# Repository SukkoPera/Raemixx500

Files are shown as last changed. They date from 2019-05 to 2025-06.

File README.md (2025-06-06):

# Rämixx500
Rämixx500 is an Open Hardware remake of the Commodore Amiga 500+ mainboard, revision 8A.1.

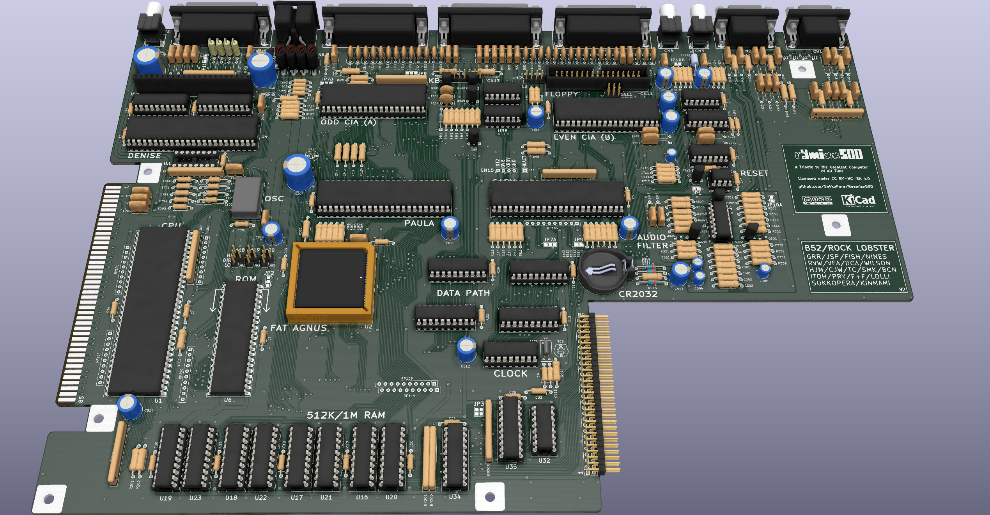
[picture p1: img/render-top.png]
Board


## Summary
Many Amiga 500+ computers are suffering an early death because of the built-in barrel battery that powers their internal real-time clocks. Such batteries have long exceeded their planned lives and in many cases have started to leak alkaline liquids over the mainboard, corroding copper traces and destroying components.

This damage can sometimes be repaired trivially, but many times it requires a lot of time and effort. Sometimes it adds up to other damage occurred over time and so it would just be better to have a new board built with new components to move the few critical chips over. Amiga mainboards haven't been produced for the last 30 years, but they are relatively simple by today's standards, thus an amateur project to make new ones was started.

There are other projects with the same goal out there, but none of them is Open Source and none of them comes with both schematics and board. This is a big advantage, since anyone can modify the board and make new improved versions, as long as they release their modifications it with the same license. I have come up with [some ideas for improvements](https://github.com/SukkoPera/Raemixx500/issues/14), feel free to help :).

The first version of the board was released in April 2020 as untested, in the hope that someone from the Amiga "Community" would jump in and help with the testing. Well, that took quite some time but in the end someone finally understood that Open Hardware is about trying to do your part rather than coming up with [heaps of useless talking and moaning](https://news.ycombinator.com/item?id=22887349) or [blatant stealing](https://retrotechlyfe.com/home/ols/products/commodore-amiga-500-computer-motherboard-logic-board-premium-gold-immersed-traces-stellar-signal-integrity) and allowed this project to reach the next milestone. So despite knowing he could be jumping into the void, fellow Italian living in Japan Edoardo Auteri put confidence, money, time and effort into assembling a board and testing it thoroughly. While he was at it, he came up with some interesting ideas which ultimately encouraged me to make Version 2, which **fully passed all tests**. You can read more about the development and testing of the board on [the official development blog](https://hackaday.io/project/180442-rmixx500-amiga-500-mainboard).

## Differences from Original
The initial objective was to come up with a new mainboard as similar to the original one as possible, while including minor modifications that would improve its usability. This mainboard was designed with *reasonable* - not *maniacal* - accuracy to the original design. Most care was taken in the positioning of components that ought to be in a certain position (i.e.: screw holes and I/O connectors), to ensure drop-in replaceability. Other components and tracks are "more or less" there, but as the board was wholly laid out from scratch by hand, don't expect sub-millimeter accuracy.

Some modifications were soon added in, in the hope that they would be useful. Let's make it clear straight from the beginning that **most of these improvements and modifications are completely optional and actually disabled by default**. This means that you can just ignore them and everything will work as it did on the original A500+ board. If you want to take advantage of them instead, you will need to do some work.

### Modifications introduced in V2
* **Buffered Video Synchronization Signals**: This will make the VSYNC and HSYNC signals going out from the DB23 connector somewhat "stronger", which should improve video quality and also allow using fully passive (i.e.: just wires) RGB to VGA cables (but please note that the signal will still be 15 kHz so a scandoubler will still be required with most VGA monitors). To enable this, cut both the JP99H/V jumpers, solder a 74HCT14 SOIC chip at U94 (yes, it's surface-mount, but the available space was limited) and a 100-330nF ceramic capacitor at C94. Note that if you want to get back to unbuffered (why???) you will **both** need to unsolder U94 and close the jumpers again, otherwise you will definitely damage your Denise and/or buffer. One small caveat: you'd better decide what to do with this mod before you solder the nearby components, as space around U94 is really tight and (un)soldering it with the other components in place is not a task for the faint-hearted.

* **ESD Protection for the Joystick Ports**: While connecting controllers blindly is **still not recommended**, you can add some diodes that *should* hopefully avoid damage to the internal chips whenever you do so. These won't hurt in any case, so why not? Just solder some AT1042 chips at U90-U93. Yes, they are small but you can make it.

* **Hard Disk LED**: If you use an internal expansion board that provides an IDE connector, you will feel the need for a LED flashing whenever the disk is accessed. If you connect a wire from pin 39 of your CF adapter to the new *HDACT* connector right in the middle of the board, the *Floppy* light will also flash when the hard disk is accessed. To get this to work, solder a 2n3906 transistor at Q99 and resistors R98 (10k) and R99 (4.7k).

* **Alternative Footprint for the Line Filter**: The original line filter (LF1) was probably a custom part, but in any case it's impossible to find these days. Luckily a functionally-equivalent part is available (Laird Z131B-10) but it has a different footprint, so the latter was added at LF99. Be **very careful** when soldering this, as it is very easy to make a solder bridge between the pads of LF1 and those of LF99 and short out the power rails.

* **Alternative SMD Footprints for the JFETs**: Q321/331 are a bit hard to find these days in the TO-92 package, so alternative surface-mount SOT-23 footprints were added (Q921/931). Choose the package you prefer and only solder one of each.

* **More Accurate Dimensions**: While V1 was already pretty close to the original board, the new version should be right on the money. Placement of the audio and mouse ports was also improved.

* **More Detailed Silkscreen**: The values of all resistors, capacitors and chips are now printed on the silkscreen, which makes the assembly process quicker and less error-prone.

* **Improved Routing and Ground Plane**: Some tracks were slightly altered in the hope of achieving improved signal integrity. Lower impedance to ground also resulted in all chips running a few degrees Celsius colder.

* One more change lies in the license: **the project is now released under CC BY-NC-SA**, which is not too different in practice from the license we were using before, except that **any commercial use is now prohibited**. I know this makes the project non-free, strictly speaking. While I am sorry for that, that's what the behaviour of the "community" has led me to. Blame them, not me.

### Modifications Introduced in V1/V1B
* **Support for VBB Agnus**: This board is compatible with a few different Fat Agnus models, namely: 318069-10 and 390544-03 for PAL or -11 and -02 for NTSC (FIXME). The 390544 models have a *VBB* marking and require a 100-330nF cap to be fitted at C99, which must instead be left unpopulated for the other models. Note that while all the mentioned models are also numbered *8375*, **not all 8375 models are actually compatible**: please check that the extended part number is one of those mentioned above (these usually came from "wide label" A500 featuring a Rev.8A mainboard, A500+ or A600 computers, if you got your Agnus somewhere else, it likely isn't the correct one). 8372 and 8371 models are definitely not compatible either at the moment. And before you ask: no, Alice chips will never work.

* **Mono Audio Link**: This feature was lifted from the A600/A1200 and will transparently downmix the audio output to mono whenever you only plug one of the two audio connectors (any of the two), while on the original A500 you would only hear the corresponding channel. Whenever you plug both connectors, the channels will separate automatically. This is the reason why this feature is enabled by default, in that it is completely transparent to the user in normal conditions.

* **Alternative Power Connector**: Besides using the original A500 power connector, which can be expensive to get hold of, you can use common and cheap DIN-6 or DIN-8 connectors. Have a look [at the wiki](https://github.com/SukkoPera/Raemixx500/wiki/Power-Connector-Wiring) for more information, including a wiring method.

* **Kickstart Switcher**: This is a set of jumpers that will allow you to store more than one Kickstart image on a single ROM chip and enable one at will. If you want to use it, have a look [at the wiki](https://github.com/SukkoPera/Raemixx500/wiki/Kickstart-Switcher).

* **Drive Switcher**: This is a pretty basic drive switcher which will result in the first external drive to be seen as DF0: and the actual DF0: to become invisible. Instructions for how to use it are on [the wiki](https://github.com/SukkoPera/Raemixx500/wiki/Drive-Switcher) as usual.

### Other Minor Things Worth Mentioning
Following is a list of deliberate changes with respect to the original layout of the A500+ rev.8A.1 board:
- The footprints for all DIP chips use "long pads". This makes them easier to solder and more solid to the board should you need to rework them. This forced a few tracks running very close to the original pads to be slightly offset away.
- The power connector footprint was altered to either accept the original connector, a DIN-6 or a DIN-8. I actually recommend the latter, as it uses more than one pin for the +5V and +12V rails, allowing for more current.
- The floppy connector footprint was changed to that of a full IDC connector.
- The barrel battery was replaced with a BS-7 battery holder for a normal (non-rechargeable) CR2032 battery. Consequently, R913 has been replaced with a diode (labeled D913) and a couple of tracks needed some displacement.
- The need to solder D912 to a leg of the former R913 has been removed. Just solder it in its place.
- The RCA jacks for the audio and composite video outputs have been replaced with some that can actually be found nowadays (i.e.: those that were used on A600/A1200). This resulted in having to relocate R409 (whose original position seemed somehow improvised anyway...).
- The silkscreen for some components does not match the original one. I used the built-in KiCad footprints as-is, when available.
- The silkscreen and pitch of C303, C304 and C306 have been made smaller so that they don't overlap.
- Speaking about the silkscreen, I have been quite liberal with it. I have used the default KiCad font and I did not follow the original label placement at all costs. I did this since today's technology can give us a bit more resolution in silkscreen printing, and I think that is worth using for the sake of clarity. Some ground stitching vias were slightly offset to make up space for labels.
- The vias inside the pads of JP10A and JP11 have been slightly offset so that they are outside the pads.
- The ground fill is autogenerated by KiCad, so it won't match the original exactly.
- Probably there's something more I've forgotten.

## Assembly and Installation
Please refer to [the wiki](https://github.com/SukkoPera/Raemixx500/wiki).

## Releases
If you want to get this board produced, you are recommended to get [the latest release](https://github.com/SukkoPera/Raemixx500/releases) rather than the current git version, as the latter might be under development and is not guaranteed to be working.

Every release is accompanied by its Bill Of Materials (BOM) file and any relevant notes about it, which you are recommended to read carefully.

**I am not providing ready-to-use gerber files**. If all you want is **to get boards made, I would really appreciate if you did so [in a way that supports the project](#support-the-project)**.

## License
The Rämixx500 documentation, including the design itself, is copyright &copy; SukkoPera 2019-2021 and is licensed under the [Creative Commons Attribution-NonCommercial-ShareAlike 4.0 International License](https://creativecommons.org/licenses/by-nc-sa/4.0/).

This documentation is distributed *as is* and WITHOUT ANY EXPRESS OR IMPLIED WARRANTIES whatsoever with respect to its functionality, operability or use, including, without limitation, any implied warranties OF MERCHANTABILITY, SATISFACTORY QUALITY, FITNESS FOR A PARTICULAR PURPOSE or infringement. We expressly disclaim any liability whatsoever for any direct, indirect, consequential, incidental or special damages, including, without limitation, lost revenues, lost profits, losses resulting from business interruption or loss of data, regardless of the form of action or legal theory under which the liability may be asserted, even if advised of the possibility or likelihood of such damages.

This said, I would like this project to progress further. **If anyone would like to do major work on it but is discouraged to do so by the impossibility to exploit the work commercially, please get in touch with me**, I will grant you a private license which will allow you to do that.

## Support the Project
There are currently no "official" sellers selling this board. If someone wants to become "official", just get in touch with me, conditions are very simple (i.e.: we agree on a price cap and you donate a fraction of your earnings to some charity of your choice, that's it).

This means that all the boards currently on sale on eBay or anywhere else are breaching the licensing terms, so you are strongly recommended not to buy from these sellers and maybe you should even report them to eBay, since they are not paying attention to me (neither the sellers themselves, nor eBay...).

The recommended way to get a board is to have some produced by PCBWay through this link:

PCB from PCBWay (https://www.pcbway.com/project/shareproject/Raemixx500_V2_5d8b0793.html)

You get my gratitude and cheap, professionally-made and good quality PCBs, I get some credit that will help with this and [other projects](https://www.pcbway.com/project/member/shareproject/?bmbid=41100). You won't even have to worry about the various PCB options, it's all pre-configured for you!

Also, if you still have to register, [you can use this link](https://www.pcbway.com/setinvite.aspx?inviteid=41100) to get some bonus initial credit (and yield me some more).

You will have to order at least 5 PCBs, but then you can share the extras with your friends or put them up for sale on forums or anywhere **at cost**.

If you think PCBWay is too expensive, just generate the Gerber files in KiCad (it takes 5 seconds, maybe 30 if you've never done it before) and order from your favourite supplier.

## Thanks
- Commodore, for making the coolest machine ever.
- [Edoardo Auteri](https://github.com/kinmami) for putting confidence in me and joining the project. He is also the person that you should be thankful to if this project is still open-source.
- [Amiga PCB Explorer](http://amigapcb.org), a fundamental tool to follow the original track placement.
- [amigawiki](https://www.amigawiki.org/doku.php?id=en:service:schematics), mainly for the schematics but also for the whole lot of information they provide.
- majinga for helping with the measuring.
- [Walter](http://smisioto.no-ip.org/elettronica/kicad/kicad-en.htm) for some of the footprints/3D models used.
- [DiagROM](http://www.diagrom.com/) for inspiring the selling clause.
- [Jason Warnes](https://www.everythingamiga.com/2019/10/alternative-to-amiga-500-600-1200-power-connector.html) for information about the original power connector and how to replace it with a DIN-8.
- [Szabó Zoltán](https://twitter.com/DeGenTd) for designing the board logo.
- [Workshopshed](https://twitter.com/Workshopshed) for the 3D models of the EMI filters.
- [StormTrooper](https://github.com/StormTrooper/Commodore-Plus4) for a few other 3D models, taken from his Plus/4 remake.

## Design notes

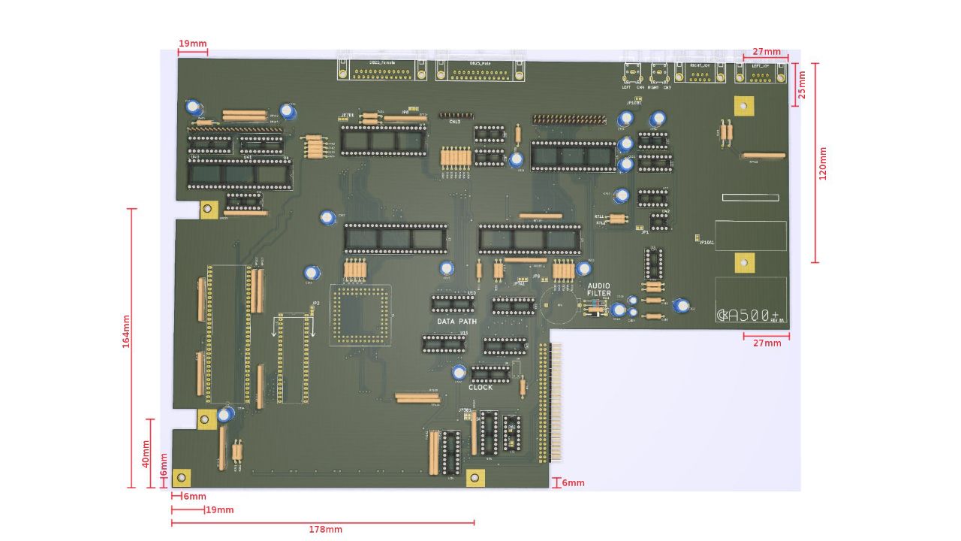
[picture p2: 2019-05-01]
doc/dimensions2.jpg

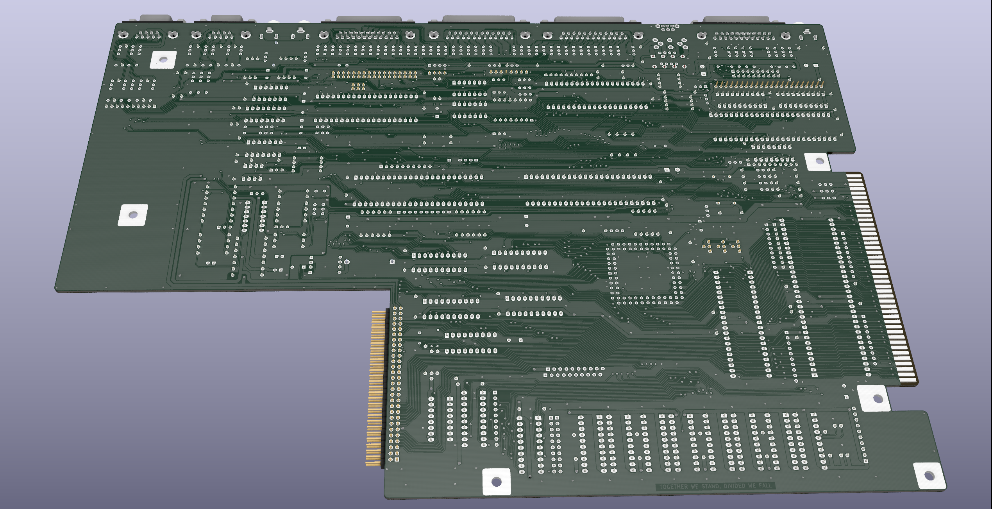
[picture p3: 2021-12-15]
img/render-bottom.png

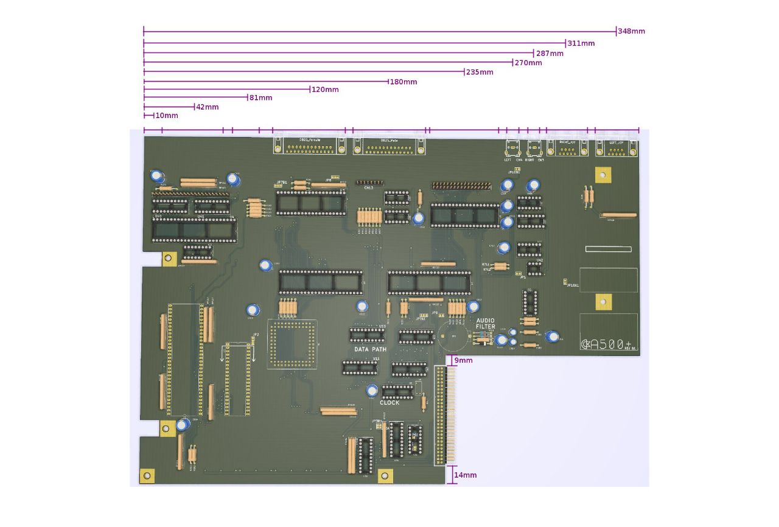
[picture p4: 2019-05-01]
doc/dimensions3.jpg

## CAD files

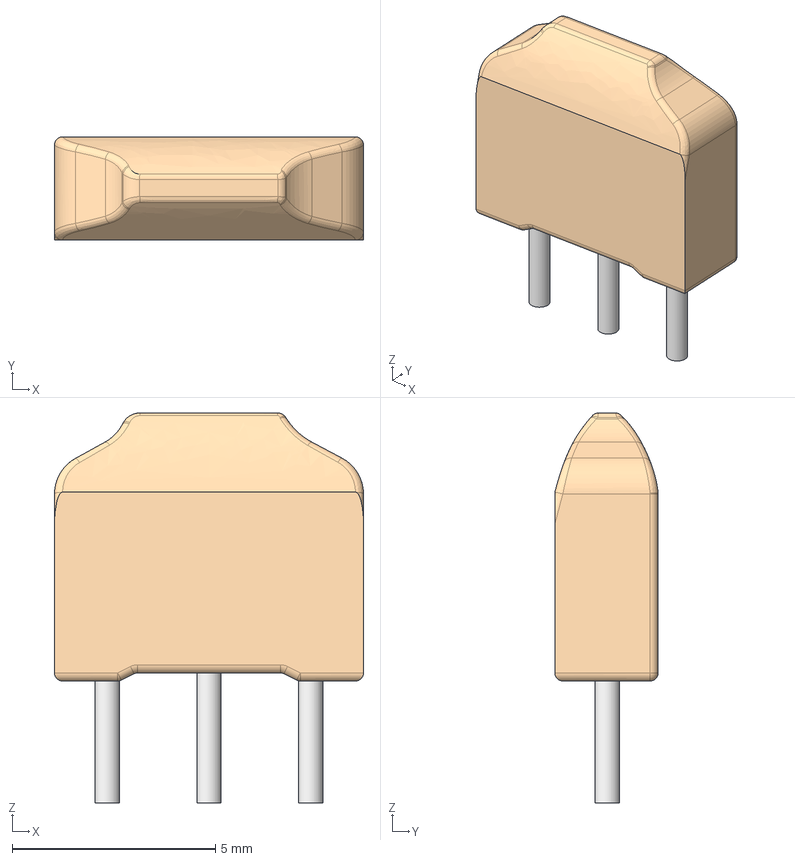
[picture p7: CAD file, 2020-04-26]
3dModels/DSS6.step
7.60 x 2.54 x 9.59 mm

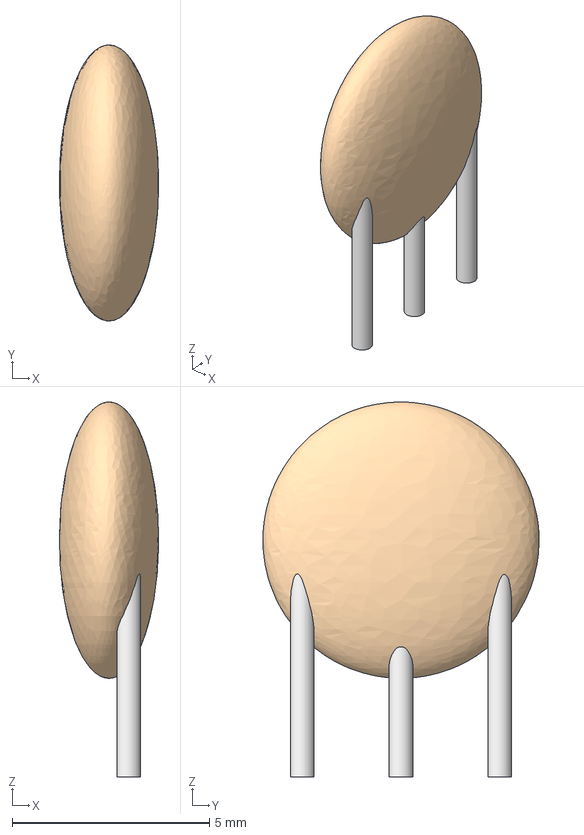
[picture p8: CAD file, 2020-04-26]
3dModels/DSN6.step
2.52 x 6.99 x 9.50 mm

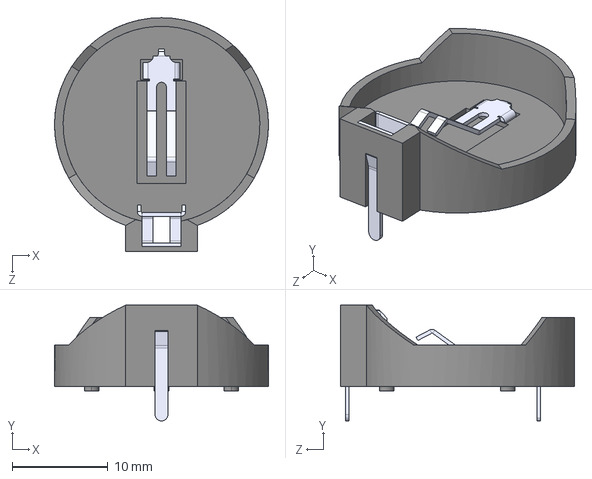
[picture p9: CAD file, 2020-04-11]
3dModels/BS-7.STEP
22.3 x 12.1 x 24.4 mm

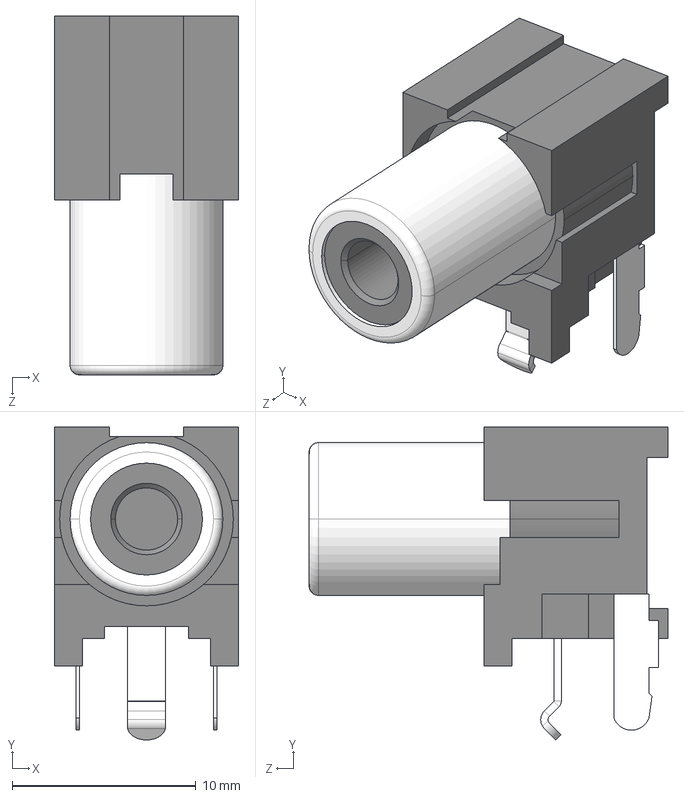
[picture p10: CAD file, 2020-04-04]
3dModels/PJRAN1X1U01X--3DModel-STEP-56544.stp
10.0 x 17.0 x 19.5 mm

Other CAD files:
3dModels/DSN6.FCStd
3dModels/DSS6.FCStd

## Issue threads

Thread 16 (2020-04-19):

C401/402

SukkoPera, 2020-04-19:
C401 and 402 (video power) are specified as 1000 uF, but these had higher values in older revs, as I've personally seen up to 3300 uF. While 1000 uF can be fine, we might change and move their footprints a bit so that physically larger caps will fit (they always had a hard time anyway, even of older boards there wasn't enough room!).

A quick search on RS shows that a diameter of 16 mm should be enough. Good candidates are Panasonic EEUFS1C332 (16V, 12.5 (Dia.) x 25mm) or EEUFS1E332L (25V, 12.5 (Dia.) x 35mm). The FS series has very low ESR. The original footprints have a diameter of 8 mm and a pitch of 5 mm.

SukkoPera, 2020-04-19:
Fitting 16mm footprints proved not trivial, so I went for 12.5mm, which required just offsetting a couple of tracks.

Hopefully this makes everybody happy.

SukkoPera, 2020-04-19:
For uniformity's sake, d1d801d also changes C307 (the only other 1000uF cap) to D12.5mm.

Closed 2020-04-19.

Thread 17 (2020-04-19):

Power Connector

SukkoPera, 2020-04-19:
What about the power connector? This is definitely nowhere to be found. Maybe we can consider DIN-5 (can carry up to 4A@24V)? In that case we should come up with a footprint that can either fit a salvaged original connector or our replacement.

SukkoPera, 2020-04-19:
Thanks to [some information](https://www.everythingamiga.com/2019/10/alternative-to-amiga-500-600-1200-power-connector.html) it turned out that the footprint of the original connector is pretty much the same as an ordinary DIN-8.

So I have designed a DIN-8 footprint with extra pads for the shielding of the original connector, and mapped the pins so that both can be used.

I have also mapped the pads so that when using the DIN-8 +5V, +12V and ground use more than one pin. This allows splitting the current and hence a connector rated for less current can be used.

Finally, a DIN-6 can probably be used as well, since it has part of the pads of a DIN-8.

Fixed in 2a31e023850b9c83ca857278059ec63f08cc8abf.

Closed 2020-04-19.

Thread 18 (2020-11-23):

Has this been tested yet?

imi2003, 2020-11-23:
Hi all

Has this board been tested yet? I have 2 broken A500+ machines that need repair both with confirmed working chipsets, I was looking at another project (A500++) but it seems that the author of that project has not released any sources.
I am willing to order up a few boards and test and report back here.
I live in the UK so i can send you a blank board if they work

regards

Imran

SukkoPera, 2020-11-23:
Hi,

no, no one has tested the board yet or, if anyone has, they never bothered to report what they found out.

It would be great if you did it, please keep me up to date. :)

MBeijer, 2020-12-16:
@imi2003 any update? :)

imi2003, 2021-01-04:
@MBeijer  sorry for the late reply, I'm just waiting for the delivery, since I'm in the UK the package has been delayed because of covid and brexit, it has been with DHL in Germany for the last 3 weeks.

Baktus79, 2021-08-25:
@imi2003 Did you test the board?

zambujal, 2021-12-29:
I will test it in 1-2 days and post it here!

Calab, 2023-01-13:
So, still untested? I have this board and I'm looking to build it but we need a proper BOM.  For example U90-94 are SMT and not part of the A500+ BOM list. Same for the battery holder.

kinmami, 2023-01-13:
https://hackaday.io/project/180442-rmixx500-amiga-500-mainboard

Fully tested

Closed 2023-01-13.

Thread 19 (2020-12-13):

Missing components in 3D

AmiManga, 2020-12-13:
I really love attention to detail in this project! This is fantastic. However I noticed that some components are missing in 3D view? For example DB ports, power connector. Am I missing something in my KiCad settings or these files are not included in the project.

SukkoPera, 2020-12-15:
The 3D model is 100% complete. Some models are included in the `3dModels` directory in the project, others come from [Walter's famous libraries](http://smisioto.no-ip.org/elettronica/kicad/kicad-en.htm). You have to download those (there's a git repo at `git://smisioto.eu/kicad_libs.git` as well), save them somewhere and add a `P3D_WALTER` path in KiCad pointing to the `modules/packages3d/walter` in that directory.

AmiManga, 2020-12-15:
Thank you for your quick reply. I was able to add missing models by following your instructions. Now my motherboard looks fully populated. I must say again, this is cleanest and most complete KiCad project I had a chance to work with so far.

SukkoPera, 2020-12-15:
Go spread the word then! :)

(Closing, thanks for your interest.)

AmiManga, 2021-01-03:
I am noticing that after adding P3D_WALTER to the patch I have all 3d elements with exeption DB25F, DB25M, RIGHT_JOY, LEFT_JOY.

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

Am I missing something?

Cheers

AmiManga, 2021-01-03:
Nevermind. Fixed it. I just changed models manually.

Ranko

SukkoPera, 2021-01-03:
You are right, I have just realized some paths need to be fixed. Reopening.

SukkoPera, 2021-01-03:
Please fetch the latest changes and let me know if this is now fixed.

Closed 2021-01-03.

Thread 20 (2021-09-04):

rebuild and partial assemble with SMDs

kipper2k, 2021-09-04:
Hi,

This is Brian, (Kipper2k).  I am wanting to create a SMD version A500+ type board and would like to add new features. TBH, i don't have the time to start from scratch and want to start off with a .sch and ,brd file so i can update and then produce gerbers with the intent of creating a partial assembly of all those little components that eat up time soldering etc.  I will release files so people can do this themselves. The cost of SMD will be much cheaper than using through hole components.

 So my questions is, Has this board been proven working, Are there any Eagle files available and lastly are you willing to share the info so i can get started.

Thanks

Brian

ZaPpi3, 2021-09-04:
I built this SMD A500+ and it works (with 8375 Agnus and DIP RAM) https://github.com/gazzmaniac/Amiga-SMD-500
There are issues with the port placements and holes also and I believe maybe still with the soldermask around U33/U32?

SukkoPera, 2021-09-04:
The files available here have been tested and proved working very well, with only a few annoyances which have been fixed already. Some improvements have also been thrown into the mix and a V2 was born. This has been tested and proved working just as well. It will be released soon but the license will be changed to non-commercial. I have the intention of releasing it under the old CERN OSHW license to any individual who does any "significant contribution", but that means they will have to share their modified sources in the same way. And "sources" means "full project files" as you can see here, not just Gerbers.

Anyway you can follow the development of the new version on my hackaday blog: https://hackaday.io/project/180442-rmixx500-amiga-500-mainboard.

kipper2k, 2021-09-05:
Hi,  Thanks for the info. I will post all my files, gerbers and eagle, and if i get ambitious i will learn kicad. It will be an a500+ board but the layout may be slightly different to allow for all the mods flying around

kipper2k, 2021-09-05:
> I built this SMD A500+ and it works (with 8375 Agnus and DIP RAM) https://github.com/gazzmaniac/Amiga-SMD-500
> There are issues with the port placements and holes also and I believe maybe still with the soldermask around U33/U32?

Can you take some HiRes pictures of top and bottom of the board so i can see closeups of components and jumpers please.

Thanks.

ZaPpi3, 2021-09-06:
You can just load the files into kicad. The BOM is also there.

________________________________
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

kipper2k, 2021-09-06:
> You can just load the files into kicad. The BOM is also there.
> […](#)
> ________________________________ From: kipper2k ***@***.***> Sent: 05 September 2021 19:40 To: SukkoPera/Raemixx500 ***@***.***> Cc: ZaPpi3 ***@***.***>; Comment ***@***.***> Subject: Re: [SukkoPera/Raemixx500] rebuild and partial assemble with SMDs (#20) I built this SMD A500+ and it works (with 8375 Agnus and DIP RAM) https://github.com/gazzmaniac/Amiga-SMD-500 There are issues with the port placements and holes also and I believe maybe still with the soldermask around U33/U32? Can you take some HiRes pictures of top and bottom of the board so i can see closeups of components and jumpers please. Thanks. — You are receiving this because you commented. Reply to this email directly, view it on GitHub<[#20 (comment)](https://github.com/SukkoPera/Raemixx500/issues/20#issuecomment-913215780)>, or unsubscribe<https://github.com/notifications/unsubscribe-auth/AFUKG4EGKEZGHCAU7LD374DUAPBS3ANCNFSM5DMYW5BA>. Triage notifications on the go with GitHub Mobile for iOS<https://apps.apple.com/app/apple-store/id1477376905?ct=notification-email&mt=8&pt=524675> or Android<https://play.google.com/store/apps/details?id=com.github.android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>.

k,i will look elsewhere, there is an issue with the gerbers and i wanted to see an actual board.

ZaPpi3, 2021-09-06:
I'm not sure what you mean. I have had boards built with the gerbers and you don't need the gerbers to load the board into kicad. You can generate new gerbers there if yours are corrupt.

________________________________
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

kipper2k, 2021-09-06:
The gerbers posted at his site are reported as being bad by jlc. i posted closeups of the errors in his gerbers on his github (that i found). I do not know kicad well enough to start tweaking his files to make gerbers as i use Eagle cad and i dont want to risk introducing more errors and submitting them to JLC.

ZaPpi3, 2021-09-06:
Ah I see. I did some adjustments 2 years ago when I generated my own gerbers.
I can't remember what I did, but it wasn't a great deal. I think some track/s that wasn't needed and some soldermask problems. I cant take any decent pictures as I made the boards in white and nothing shows up. I could possibly look for the files I used but it might take me some time.

________________________________
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

kipper2k, 2021-09-06:
No worries, i will use my eagle files and cross reference his. I intend on doing the partial assembly too so  whoever wants to get most of it soldered should be able to at JLC

Closed 2024-03-25.

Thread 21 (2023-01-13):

Linked BOM does not identify all components

Calab, 2023-01-13:
In the wiki, we are told to reference an A500+ bill of material for a parts list. This BOM does not contain all the necessary components to complete this board. U90-94 and the coin battery holder for example. We could really use a proper BOM, or at least a list of differences between the A500+ and this board.

My current issue is: What package sizes are the SMT U90-94?

kinmami, 2023-01-13:
U90-94 are DT1042-04SO-7	ESD protection. Can be found on Mouser or Digikey

Calab, 2023-01-13:
U94 is a 74HCT14... Not sure of the package size on this one.

Calab, 2023-01-14:
I purchased a few different boards from Keith Dumoulin on Facebook.

sgerzack, 2023-01-14:
I will be using a VBB angus . So the 100nf cap is required I believe ?

sgerzack, 2023-01-14:
> U94 is a 74HCT14... Not sure of the package size on this one.

I used MM74HCT14MX  Got it from Digikey

SukkoPera, 2023-01-14:
Then go ask Keith Dumoulin for the BOM and any help you might. He has to provide that since he's the one who got your money. I'm fed up with these people only taking and never giving back to open projects.

Calab, 2023-01-15:
> Then go ask Keith Dumoulin for the BOM and any help you might need. He has to provide that since he's the one who got your money. I'm fed up with these people only taking and never giving back to open projects. Not to mention that the license for V2 actually even prohibits commercial use so he couldn't sell the board in the first place.

Uhm... he only had the one board and decided that he wasn't going to use it, hence he posted it for sale with some other stuff.

I don't know if he bought it from you originally, or from some other source. I assume from your hostility that you developed the board to make a profit, since that seems to be what has you upset. Myself, I'm just trying to enjoy the Amiga scene. Why else would I spend more money building a machine that it would cost just to buy a whole Amiga 500+?

Personally, I think designing a board, then refusing to provide a proper BOM is just asking for trouble in the first place.

SukkoPera, 2023-01-15:
Sure, I released ~3 years worth of work under an open license in order to make BIG MONEY! How smart of me! I surely wouldn't have released anything if I had known how dumb the Amiga scene is. All it deserves is things to be shut in drawers and lost forever.

Silveriomrs, 2023-01-15:
> Sure, I released ~3 years worth of work under an open license in order to make BIG MONEY! How smart of me! I surely wouldn't have released anything if I had known how dumb the Amiga scene is. All it deserves is things to be shut in drawers and lost forever.

Thank you for your work.
Advice... don't pay a penny for negative comments. Someone who developed something for free and openly have not to give support till the end of his life.

One thing is to understand personal frustration from some users, and other thing is to waste time answering disrespectful comments.

Calab, 2023-01-15:
> Sure, I released ~3 years worth of work under an open license in order to make BIG MONEY! How smart of me! I surely wouldn't have released anything if I had known how dumb the Amiga scene is. All it deserves is things to be shut in drawers and lost forever.

I apologize for the tone of these postings. I really do appreciated this project and plan to contribute where I can. I had never heard of the project until someone offered me the chance to by his board from him. He's not a commercial producer (that I know of).

I simply opened this issue ticket because I found a shortcoming. I wasn't demanding support or expecting anything to happen right away. The new parts are SMT so should be installed before the through hole components, and I don't know anything about package sizes for SMT parts, so I mentioned them.

I am putting together a proper BOM that can be used by this project, but all I've done is look at the board. I still need to assemble it to find out what is different and what isn't in the linked BOM.

I know you didn't do this to make a profit. I know that it's something that you fit into your spare time. I appreciate that. Please continue to do what you love and share it so others can enjoy it as well.

Take care

SukkoPera, 2023-01-15:
Thanks for the sympathy @Silveriomrs. I am actually keen on supporting this and all my other projects when it comes to improvement offers or building something new on (part of) them, but much less so when I do the work and selfish others get the money. It frustrates me *a lot* when people cannot tell the good from the bad, and it seems no one from the Amiga "community" can.

@Calab: The A500++ BOM and the notes in the README of this project are all you need to build this board.

SukkoPera, 2023-02-06:
Oh, I didn't know that. Sadly no-one else has asked for the authorization to sell the board, so I'm afraid your only choice at the moment is to buy 5 from PCBWay and sell the excess ones (I don't care if you do it at cost). Maybe sordan will restock, I don't know, they haven't for me since a long time.

**All** the boards you can find on eBay are from people who are too smart to care for licenses, by the way.

However it ends, thanks for even just bothering to ask, it's a nice gesture to at least **try** to support the original authors :).

Closed 2023-01-14.

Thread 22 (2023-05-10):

BOM like Amiga 500+ Project (Excel-sheet is based on that and completely altered to Raemixx500 project)

BrandonQuest, 2023-05-10:
I just made the mentioned list.
But I must confess:
On one hand it's based on the goal to be as close as possible to the Amiga 500+ technology,
on the other hand it's driven by the will to use as superior parts as possible to make it as "shiny" as
it deserves. The means higher quality parts, also gold plated contacts, sockets and connectors - where possible
(and that is mostly the case) no flash-golded parts, but 0,76 um).

Parts sum up to about 300€ - this could be lowered of course by chosing cheaper parts!

In addition to the Excel there are two links to Mouser and Digi-Key that - combined with each other - contain nearly the hole BOM available at the moment.

Some Parts are missing and are sourced from ebay- as there are 28.37516 MHz crystal, original RTC-Chip and related to that Murata Varicap-Trimmer .

Many comments are in the sheet, so read carefully.
Suppliers are: Digi-Key, Mouser, RS Components and Individual Computers (for a few Amiga-Connectors).
[Raemixx500 BOM.xlsx](https://github.com/SukkoPera/Raemixx500/files/11444551/Raemixx500.BOM.xlsx)

https://www.digikey.de/de/mylists/list/31UJW056MM

https://www.mouser.de/ProjectManager/ProjectDetail.aspx?AccessID=ea7761acb0

SukkoPera, 2023-05-12:
Thanks a lot for your contribution!

BrandonQuest, 2023-05-12:
Just feels good to give a little bit in return.Am 12.05.2023 um 08:14 schrieb Giorgioggì ***@***.***>:
Thanks a lot for your contribution!

—Reply to this email directly, view it on GitHub, or unsubscribe.You are receiving this because you authored the thread.Message ID: ***@***.***>

SukkoPera, 2023-05-12:
I really wish there were more people like you.

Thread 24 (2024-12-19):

seller link invalid

bigmac5753, 2024-12-19:
The link to the EU seller no longer works, is there anywhere I can purchase a single unpopulated board in UK?

SukkoPera, 2024-12-19:
Unfortunately no, there is no seller interested in selling this thing at the moment. Best solution is to get your own boards manufactured and sell the excess (at cost).

Closed 2024-12-19.

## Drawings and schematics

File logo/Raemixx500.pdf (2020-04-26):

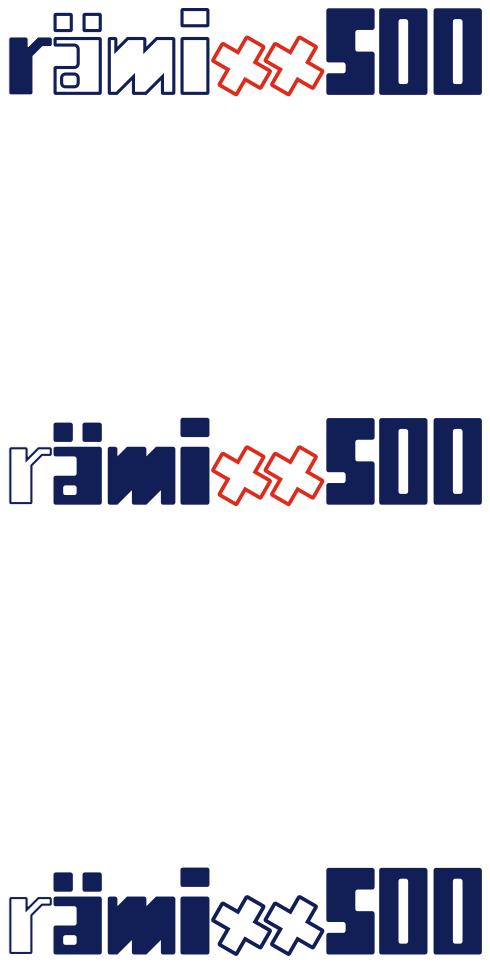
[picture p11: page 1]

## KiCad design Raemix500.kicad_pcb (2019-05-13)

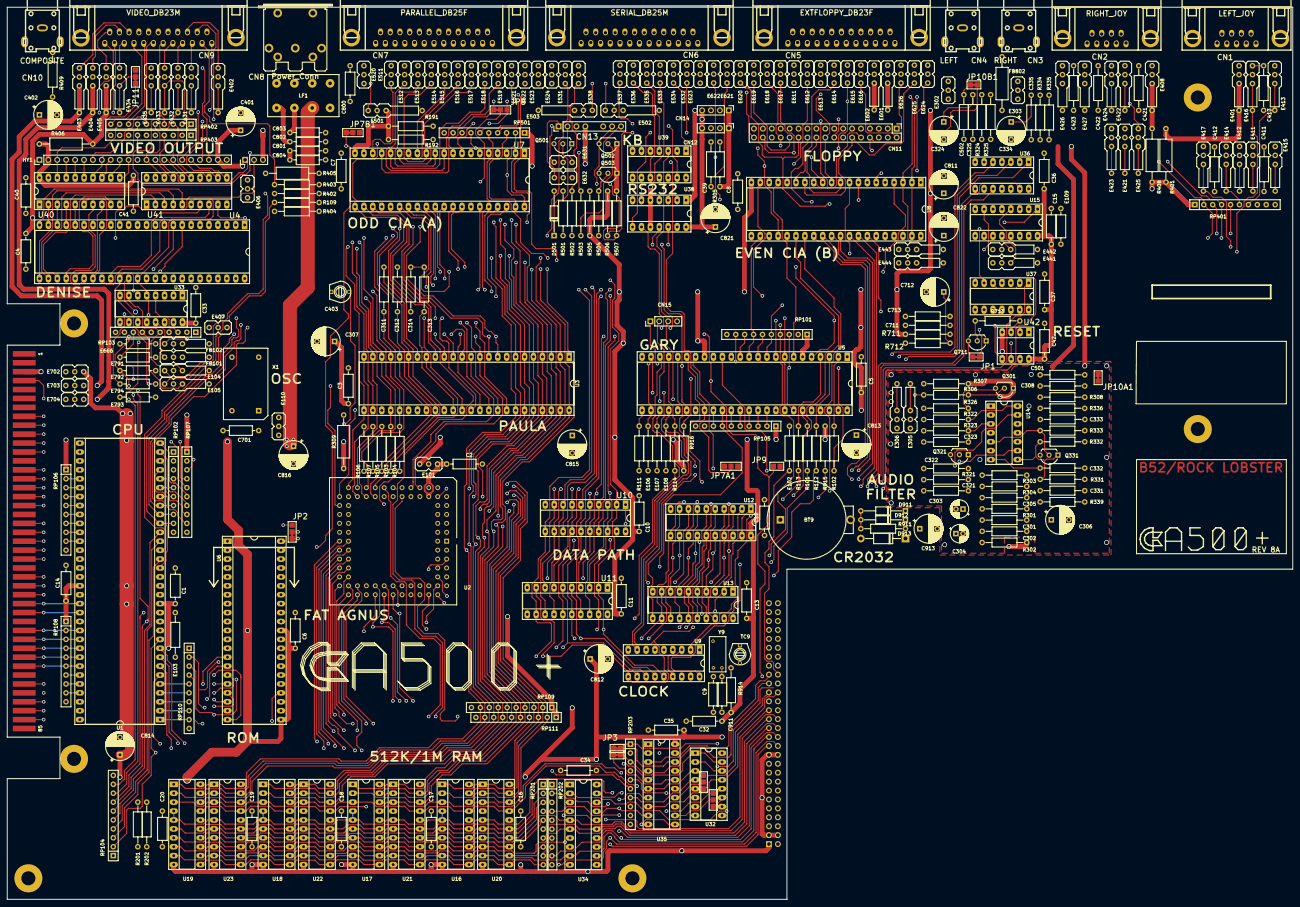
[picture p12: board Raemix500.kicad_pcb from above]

Board: 2 copper layers, 366.0 x 254.0 mm, 349 parts (1 on the bottom side), 459 nets.

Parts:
BT9: CR2032; Battery_Holder_Coin_2032_BS-7
C1, C2, C3, C4, C5, C6, C9, C11, C13, C14, C16, C17, C18, C19, C20, C40, C41, C42, C804: 330n; C_Axial_L6.3mm_D2.5mm_P10.16mm
C7, C8, C10, C12, C15, C32, C33, C34, C35, C36, C37, C701, C800, C801, C802, C803: 10n; C_Axial_L6.3mm_D2.5mm_P10.16mm
C39, C308, C713: 10n; C_Axial_L9.0mm_D3.2mm_P12.70mm
C301, C302, C305, C325, C335, C501, C502: 330n; C_Axial_L9.0mm_D3.2mm_P12.70mm
C303, C304: 22u; CP_Radial_D5.0mm_P2.00mm
C306, C712: 10u; CP_Radial_D8.0mm_P5.00mm
C307, C401, C402: 1000u; CP_Radial_D8.0mm_P5.00mm
C311, C312, C313, C314: 47n; C_Axial_L9.0mm_D3.2mm_P12.70mm
C321, C331, C711: 100n; C_Axial_L9.0mm_D3.2mm_P12.70mm
C322, C332: 6800p; C_Axial_L9.0mm_D3.2mm_P12.70mm
C323, C333: 3900p; C_Axial_L9.0mm_D3.2mm_P12.70mm
C324, C334: 22u; CP_Radial_D8.0mm_P5.00mm
C403: 47P; VariCap
C411, C412, C413, C421, C422, C423: 1000p; C_Axial_L9.0mm_D3.2mm_P12.70mm
C811, C812, C813, C814, C815, C816: 100u; CP_Radial_D8.0mm_P5.00mm
C821, C822: 47u; CP_Radial_D8.0mm_P5.00mm
C911: 22p; C_Axial_L6.3mm_D2.5mm_P10.16mm
C913: 4.7u; CP_Radial_D8.0mm_P5.00mm
CN1: LEFT_JOY; DB_9M
CN2: RIGHT_JOY; DB_9M
CN3: RIGHT; rca_red
CN4: LEFT; rca_white
CN5: EXTFLOPPY_DB23F; DB_23
CN6: SERIAL_DB25M; DB_25M
CN7: PARALLEL_DB25F; DB_25M
CN8: Power_Conn; din-5
CN9: VIDEO_DB23M; DB_23
CN10: COMPOSITE; rca_yellow
CN11: INTERNAL_FLOPPY; PinHeader_2x17_P2.54mm_Vertical
CN12: FLOPPY_POWER; PinHeader_1x04_P2.54mm_Vertical
CN13: KEYBOARD; PinHeader_1x08_P2.54mm_Vertical
CN14: IDE_POWER; PinHeader_1x04_P2.54mm_Vertical
CN15: IDE_I/F; PinHeader_1x04_P2.54mm_Vertical
D501: 1N4148; D_DO-35_SOD27_P12.70mm_Horizontal
D911, D912: 1n4148; D_DO-35_SOD27_P12.70mm_Horizontal
D913: 1n5817; D_DO-41_SOD81_P12.70mm_Horizontal
E101, E110, E406, E407, E702, E703, E704: 10n; EMI_Filter_Short
E102, E103, E106, E107, E108: 47p; C_Axial_L9.0mm_D3.2mm_P12.70mm
E104, E105: 68; EMI_Filter_Long
E109, E791, E792, E793, E794: 47p; C_Axial_L6.3mm_D2.5mm_P10.16mm
E302, E303: 6800p; EMI_Filter_Short
E305, E306: 270p; EMI_Filter_Long
E401, E403, E404, E405, E408, E601, E602: 10n; EMI_Filter_Long
E402, E434: 150p; EMI_Filter_Long
E411, E412, E413, E414, E421, E422, E423, E424: 6800p; EMI_Filter_Long
E415, E416, E417, E425, E426, E427, E441, E442, E443, E444: 470p; EMI_Filter_Long
E431, E432, E433, E435: FERR; EMI_Filter_Long
E501, E502, E503: 47 1/2W; EMI_Filter_Longer
E511, E512, E513, E514, E515, E516, E517, E518, E519, E521, E522, E523, E524, E611, E612, E613, E614, E615, E616, E617, E618, E619, E620, E621, E622, E623, E624, E625, E626, E631, E632: 100p; EMI_Filter_Short
E520, E531, E533, E535, E536, E537, E538: 470p; EMI_Filter_Short
E532, E534: 150p; EMI_Filter_Short
E666: 22p; C_Axial_L6.3mm_D2.5mm_P10.16mm
FB101: 68; EMI_Filter_Long
FB102: 150; EMI_Filter_Long
FB802: Ferrite_Bead_Small; Ferrite_Axial_L9.0mm_D3.2mm_P12.70mm
HY1: VIDIOT; PinHeader_1x22_P2.54mm_Vertical
HY2: COLOR_ANNEX; PinHeader_1x03_P2.54mm_Vertical
JP1, JP3A1, JP3B1, JP10A1, JP10B1: Jumper_2_Bridged; Jumper2-Bridged
JP2, JP8: Jumper_3_Bridged23; Jumper3-Bridged23
JP7A1: Jumper_3_Bridged12; Jumper3-Open
JP7B1, JP11: Jumper_3_Bridged12; Jumper3-Bridged12
JP9: Jumper_2_Open; Jumper2-Open
JPA4: Jumper_3_Open; Jumper3-Open
JPB4: Jumper_3_Open; Jumper3-Open
LF1: L; LineFilter
MT1, MT2, MT4, MT5, MT6, MT7: MountingHole_Pad; MountingHole_4mm_Pad
P1: EXPANSION BUS; A2000_COPRO_SLOT
P9: TRAPDOOR; PinHeader_2x28_P2.54mm_Horizontal
Q301, Q502, Q503: 2N3906; TO-92L_Inline_Wide
Q321, Q331: MPF102; TO-92L_Inline_Wide
Q501, Q711: 2N3904; TO-92L_Inline_Wide
R101, R102: 27; R_Axial_DIN0309_L9.0mm_D3.2mm_P12.70mm_Horizontal
R103, R104, R105, R106, R107, R113: 47; R_Axial_DIN0309_L9.0mm_D3.2mm_P12.70mm_Horizontal
R109, R111, R112, R114: 68; R_Axial_DIN0309_L9.0mm_D3.2mm_P12.70mm_Horizontal
R191, R192, R303, R304, R305, R324, R334, R713, R915, R916: 1k; R_Axial_DIN0309_L9.0mm_D3.2mm_P12.70mm_Horizontal
R201, R202, R402, R403, R404, R503, R504: 4.7k; R_Axial_DIN0309_L9.0mm_D3.2mm_P12.70mm_Horizontal
R301, R302: 10; R_Axial_DIN0309_L9.0mm_D3.2mm_P12.70mm_Horizontal
R306, R308, R322, R323, R332, R333, R339, R501, R505, R506, R914: 10k; R_Axial_DIN0309_L9.0mm_D3.2mm_P12.70mm_Horizontal
R307, R502: 2.7k; R_Axial_DIN0309_L9.0mm_D3.2mm_P12.70mm_Horizontal
R309: 10; R_Axial_DIN0309_L9.0mm_D3.2mm_P15.24mm_Horizontal
R321, R331: 360; R_Axial_DIN0309_L9.0mm_D3.2mm_P12.70mm_Horizontal
R325, R335: 390; R_Axial_DIN0309_L9.0mm_D3.2mm_P12.70mm_Horizontal
R326, R336: 470k; R_Axial_DIN0309_L9.0mm_D3.2mm_P12.70mm_Horizontal
R401, R406, R408: 4.7; R_Axial_DIN0309_L9.0mm_D3.2mm_P15.24mm_Horizontal
R405: 0.47; R_Axial_DIN0309_L9.0mm_D3.2mm_P15.24mm_Horizontal
R409: 150; C_Axial_L9.0mm_D3.2mm_P12.70mm
R507: 100; R_Axial_DIN0309_L9.0mm_D3.2mm_P12.70mm_Horizontal
R711: 1M; R_Axial_DIN0309_L9.0mm_D3.2mm_P12.70mm_Horizontal
R712: 47K; R_Axial_DIN0309_L9.0mm_D3.2mm_P12.70mm_Horizontal
R911: 470; R_Axial_DIN0309_L9.0mm_D3.2mm_P12.70mm_Horizontal
RP101, RP102, RP104, RP105, RP106, RP107, RP108, RP109, RP110, RP111: 4.7k; R_Array_SIP10
RP103: 39; R_Array_SIP10
RP201, RP202, RP203: 68; R_Array_SIP10
RP401: 4.7K; R_Array_SIP10
RP402, RP403: 47; R_Array_SIP10
RP501: 10k; R_Array_SIP10
TC9: 6.8-45p; VariCap
U1: 68000D; DIP-64_W22.86mm_Socket_LongPads
U2: FAT_AGNUS_8375; PLCC-84_THT-Socket
U3: PAULA; DIP-48_W15.24mm_Socket_LongPads
U4: DENISE; DIP-48_W15.24mm_Socket_LongPads
U5: GARY_5719; DIP-48_W15.24mm_Socket_LongPads
U6: ROM; DIP-42_W15.24mm_Socket_LongPads
U7, U8: VIA_8520; DIP-40_W15.24mm_Socket_LongPads
U9: MSM6242B; DIP-18_W7.62mm_Socket_LongPads
U10, U12, U35: 74LS244; DIP-20_W7.62mm_Socket_LongPads
U11, U13, U34: 74LS373; DIP-20_W7.62mm_Socket_LongPads
U14: LF347; DIP-14_W7.62mm_Socket_LongPads
U15: 74LS157; DIP-16_W7.62mm_Socket_LongPads
U16, U17, U18, U19, U20, U21, U22, U23: XX4256; DIP-20_W7.62mm_Socket_LongPads
U32: 74LS139; DIP-16_W7.62mm_Socket_LongPads
U33: 74LS258; DIP-16_W7.62mm_Socket_LongPads
U36: 74LS05; DIP-14_W7.62mm_Socket_LongPads
U37: 74LS32; DIP-14_W7.62mm_Socket_LongPads
U38: MC1488; DIP-14_W7.62mm_Socket_LongPads
U39: MC1489; DIP-14_W7.62mm_Socket_LongPads
U40, U41: 74LS245; DIP-20_W7.62mm_Socket_LongPads
U42: NE555; DIP-8_W7.62mm_Socket_LongPads
X1: XTAL; Xtal
Y9: 32768 Hz; Crystal_RTC

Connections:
7MHZ: E103.1, P1.7, R106.1, U1.15
7MHZ_A: C403.1, E794.1, R107.1, U4.35
+12V: C802.1, C821.1, CN12.4, CN14.4, E404.1, E502.1, E602.1, E704.1, HY2.3, LF1.5, P9.55, R301.1, R911.2, U38.14
+VDC: C301.1, C303.1, Q301.1, R301.2, R307.2, U14.4
-12V: C803.2, C822.2, E403.1, E503.1, E703.1, LF1.6, P9.56, R302.2, U38.1
-VDC: C302.2, C304.2, R302.1, R308.2, U14.11
/Denise & Video Stuff/ab: E433.1, HY1.17
/Denise & Video Stuff/ag: E432.1, HY1.12
/Denise & Video Stuff/ar: E431.1, HY1.7
/Denise & Video Stuff/bb0: HY1.16, RP402.3, U41.15
/Denise & Video Stuff/bb1: HY1.15, U41.16
/Denise & Video Stuff/bb2: HY1.14, U41.17
/Denise & Video Stuff/bb3: HY1.13, RP402.5, U41.18
/Denise & Video Stuff/bcck: HY2.1, RP403.4, U41.14
/Denise & Video Stuff/bcsync_a: RP403.9, U41.12
/Denise & Video Stuff/bcsync_b: HY1.18, U41.11
/Denise & Video Stuff/bg0: HY1.11, U40.11
/Denise & Video Stuff/bg1: HY1.10, U40.12
/Denise & Video Stuff/bg2: HY1.9, U40.13
/Denise & Video Stuff/bg3: HY1.8, RP402.7, U40.14
/Denise & Video Stuff/bpixelsw: RP402.1, U41.13
/Denise & Video Stuff/br0: HY1.6, U40.15
/Denise & Video Stuff/br1: HY1.5, U40.16
/Denise & Video Stuff/br2: HY1.4, U40.17
/Denise & Video Stuff/br3: HY1.3, RP402.9, U40.18
/Denise & Video Stuff/cck_c: E402.1, RP403.3
/Denise & Video Stuff/csync_out: E434.1, JP11.2
/Denise & Video Stuff/rbcsync_a: JP11.1, RP403.10
/Parallel & Serial/+v: CN6.9, E502.3
/Parallel & Serial/-v: CN6.10, E503.3
/Parallel & Serial/cd: CN6.8, E537.3
/Parallel & Serial/clock: CN13.1, E632.1
/Parallel & Serial/cts: CN6.5, E535.3
/Parallel & Serial/data: CN13.2, E631.1
/Parallel & Serial/dsr: CN6.6, E536.3
/Parallel & Serial/dtr: CN6.20, E531.3
/Parallel & Serial/inuse: CN13.8, Q503.3
/Parallel & Serial/pp0: E512.1, U7.10
/Parallel & Serial/pp1: E513.1, U7.11
/Parallel & Serial/pp2: E514.1, U7.12
/Parallel & Serial/pp3: E515.1, U7.13
/Parallel & Serial/pp4: E516.1, U7.14
/Parallel & Serial/pp5: E517.1, U7.15
/Parallel & Serial/pp6: E518.1, U7.16
/Parallel & Serial/pp7: E519.1, U7.17
/Parallel & Serial/rts: CN6.4, E533.3
/Parallel & Serial/rxd: CN6.3, E534.3
/Parallel & Serial/status: CN13.7, Q502.3, R507.1
/Parallel & Serial/txd: CN6.2, E532.3
/Parallel & Serial/~auto: CN7.14, E501.3
/Parallel & Serial/~init: CN7.16, E520.3
/Paula & Audio Stuff/left: E306.1, U3.31
/Paula & Audio Stuff/pot0x: C311.1, E417.3, U3.32
/Paula & Audio Stuff/pot0y: C312.1, E416.1, U3.33
/Paula & Audio Stuff/pot1x: C313.1, E427.3, U3.35
/Paula & Audio Stuff/pot1y: C314.1, E426.3, U3.36
/Paula & Audio Stuff/right: E305.1, U3.30
/RAM/ma0: RP202.3, U16.6, U17.6, U18.6, U19.6, U20.6, U21.6, U22.6, U23.6
/RAM/ma1: RP202.5, U16.7, U17.7, U18.7, U19.7, U20.7, U21.7, U22.7, U23.7
/RAM/ma2: RP202.7, U16.8, U17.8, U18.8, U19.8, U20.8, U21.8, U22.8, U23.8
/RAM/ma3: RP202.10, U16.9, U17.9, U18.9, U19.9, U20.9, U21.9, U22.9, U23.9
/RAM/ma4: RP201.10, U16.11, U17.11, U18.11, U19.11, U20.11, U21.11, U22.11, U23.11
/RAM/ma5: RP201.8, U16.12, U17.12, U18.12, U19.12, U20.12, U21.12, U22.12, U23.12
/RAM/ma6: RP201.5, U16.13, U17.13, U18.13, U19.13, U20.13, U21.13, U22.13, U23.13
/RAM/ma7: RP201.3, U16.14, U17.14, U18.14, U19.14, U20.14, U21.14, U22.14, U23.14
/RAM/ma8: RP202.1, U16.15, U17.15, U18.15, U19.15, U20.15, U21.15, U22.15, U23.15
/RAM/~bcasl0: JPA4.1, RP203.7, U32.4
/RAM/~bcasu0: JPB4.1, RP203.5, U32.12
A1: P1.29, RP107.9, U1.29, U2.60, U6.10
A2: P1.27, P9.45, RP107.8, U1.30, U2.61, U6.9, U9.4
A3: P1.26, P9.46, RP107.7, U1.31, U2.62, U6.8, U9.5
A4: P1.24, P9.47, RP107.6, U1.32, U2.63, U6.7, U9.6
A5: P1.21, P9.48, RP107.5, U1.33, U2.64, U6.6, U9.7
A6: P1.23, RP107.4, U1.34, U2.65, U6.5
A7: P1.28, RP107.2, U1.35, U2.66, U6.4
A8: P1.30, RP107.3, U1.36, U2.67, U6.3, U7.38, U8.38
A9: P1.32, RP106.2, U1.37, U2.68, U6.41, U7.37, U8.37
A10: P1.34, RP106.3, U1.38, U2.69, U6.40, U7.36, U8.36
A11: P1.36, RP106.4, U1.39, U2.70, U6.39, U7.35, U8.35
A12: P1.38, RP106.5, U1.40, U2.71, U6.38, U37.1
A13: P1.39, RP106.6, U1.41, U2.72, U6.37, U37.4
A14: P1.41, RP106.7, U1.42, U2.73, U6.36
A15: P1.43, RP106.8, U1.43, U2.74, U6.35, U36.13
A16: P1.45, RP106.9, U1.44, U2.75, U6.34
A17: P1.47, RP105.8, U1.45, U2.76, U5.33, U6.33
A18: P1.52, RP105.7, U1.46, U2.77, U5.34, U6.2
A19: JP2.3, P1.54, RP105.6, U1.47, U5.35, U6.1
A20: P1.56, RP105.5, U1.48, U2.35, U5.36, U6.42
A21: P1.58, RP105.4, U1.50, U5.37
A22: P1.57, RP105.3, U1.51, U5.38
A23: JP2.1, P1.59, RP105.2, U1.52, U5.39
AUDIN: C501.1, JP10A1.1
AUDOUT: C502.2, JP10B1.2
BDRA0: P9.23, RP202.4, U35.9
BDRA1: P9.24, RP202.6, U35.7
BDRA2: P9.25, RP202.8, U34.9
BDRA3: P9.26, RP202.9, U34.19
BDRA4: P9.27, RP201.9, U34.16
BDRA5: P9.28, RP201.7, U34.6
BDRA6: P9.29, RP201.6, U34.15
BDRA7: P9.30, RP201.4, U34.5
BDRA8: P9.31, RP202.2, U34.12
BDRA9: U32.2, U32.14, U34.2
CCK: E108.1, R103.1, U3.28, U4.36, U5.28, U33.5, U33.6, U35.15, U41.6
CCKQ: E107.1, R104.1, U3.29, U5.27, U33.10, U33.11
CDAC: E793.1, P1.15, RP103.4
D0: P1.75, P9.41, RP110.5, U1.5, U6.14, U7.33, U8.33, U9.14, U10.2, U11.2
D1: P1.77, P9.42, RP110.6, U1.4, U6.16, U7.32, U8.32, U9.13, U10.4, U11.5
D2: P1.79, P9.43, RP110.7, U1.3, U6.18, U7.31, U8.31, U9.12, U10.6, U11.6
D3: P1.81, P9.44, RP110.8, U1.2, U6.20, U7.30, U8.30, U9.11, U10.8, U11.9
D4: P1.83, RP110.9, U1.1, U6.23, U7.29, U8.29, U10.11, U11.12
D5: P1.86, RP110.4, U1.64, U6.25, U7.28, U8.28, U10.13, U11.15
D6: P1.84, RP110.3, U1.63, U6.27, U7.27, U8.27, U10.15, U11.16
D7: P1.82, RP110.2, U1.62, U6.29, U7.26, U8.26, U10.17, U11.19
D8: P1.80, RP108.9, U1.61, U6.15, U12.2, U13.2
D9: P1.78, RP108.8, U1.60, U6.17, U12.4, U13.5
D10: P1.76, RP108.7, U1.59, U6.19, U12.6, U13.6
D11: P1.71, RP108.6, U1.58, U6.21, U12.8, U13.9
D12: P1.69, RP108.5, U1.57, U6.24, U12.11, U13.12
D13: P1.67, RP108.4, U1.56, U6.26, U12.13, U13.15
D14: P1.65, RP108.3, U1.55, U6.28, U12.15, U13.16
D15: P1.63, RP108.2, U1.54, U6.30, U12.17, U13.19
DIR: CN11.18, E623.1, U8.11
DKWE: U3.39, U5.8
DMAL: U2.18, U3.12
DRA0: U2.42, U35.11
DRA1: U2.43, U35.13
DRA2: U2.44, U34.8
DRA3: U2.45, U34.18
DRA4: U2.46, U34.17
DRA5: U2.47, U34.7
DRA6: U2.48, U34.14
DRA7: U2.49, U34.4
DRA8: U2.50, U34.13
DRA9: U2.55, U34.3
DRD0: P9.5, RP111.2, U2.14, U3.10, U4.7, U10.18, U11.3, U16.18, U20.18
DRD1: P9.6, RP109.2, U2.13, U3.9, U4.6, U10.16, U11.4, U16.2, U20.2
DRD2: P9.7, RP111.3, U2.12, U3.7, U4.5, U10.14, U11.7, U16.19, U20.19
DRD3: P9.8, RP109.3, U2.11, U3.6, U4.4, U10.12, U11.8, U16.1, U20.1
DRD4: P9.9, RP111.4, U2.10, U3.5, U4.3, U10.9, U11.13, U17.18, U21.18
DRD5: P9.10, RP109.4, U2.9, U3.4, U4.2, U10.7, U11.14, U17.2, U21.2
DRD6: P9.11, RP111.5, U2.8, U3.3, U4.1, U10.5, U11.17, U17.19, U21.19
DRD7: P9.12, RP109.5, U2.7, U3.2, U4.48, U10.3, U11.18, U17.1, U21.1
DRD8: P9.13, RP111.6, U2.6, U3.1, U4.47, U12.18, U13.3, U18.18, U22.18
DRD9: P9.14, RP109.6, U2.5, U3.48, U4.46, U12.16, U13.4, U18.2, U22.2
DRD10: P9.15, RP111.7, U2.4, U3.47, U4.45, U12.14, U13.7, U18.19, U22.19
DRD11: P9.16, RP109.7, U2.3, U3.46, U4.44, U12.12, U13.8, U18.1, U22.1
DRD12: P9.17, RP111.8, U2.2, U3.45, U4.43, U12.9, U13.13, U19.18, U23.18
DRD13: P9.18, RP109.8, U2.1, U3.44, U4.42, U12.7, U13.14, U19.2, U23.2
DRD14: P9.19, RP111.9, U2.84, U3.43, U4.41, U12.5, U13.17, U19.19, U23.19
DRD15: P9.20, RP109.9, U2.83, U3.42, U4.40, U12.3, U13.18, U19.1, U23.1
E: P1.50, R109.2, U1.20
FC0: P1.31, RP102.4, U1.28
FC1: P1.33, RP102.5, U1.27
FC2: P1.35, RP102.6, U1.26
GND: BT9.2, C1.2, C2.2, C3.2, C4.2, C5.2, C6.2, C7.2, C8.2, C9.2, C10.2, C11.2, C12.2, C13.2, C14.2, C15.2, C16.2, C17.2, C18.2, C19.2, C20.2, C32.2, C33.2, C34.2, C35.2, C36.2, C37.2, C39.2, C40.2, C41.2, C42.2, C307.2, C401.2, C402.2, C403.2, C411.2, C412.2, C413.2, C421.2, C422.2, C423.2, C701.2, C711.2, C712.2, C713.2, C801.2, C802.2, C803.1, C804.2, C811.2, C812.2, C813.2, C814.2, C815.2, C816.2, C821.2, C822.1, C911.1, C913.2, CN1.8, CN2.8, CN3.2, CN4.2, CN5.3, CN5.4, CN5.5, CN5.6, CN5.7, CN6.7, CN7.17, CN7.18, CN7.19, CN7.20, CN7.21, CN7.22, CN7.23, CN7.24, CN7.25, CN8.2, CN9.13, CN9.16, CN9.17, CN9.18, CN9.19, CN9.20, CN10.2, CN11.1, CN11.5, CN11.7, CN11.9, CN11.11, CN11.13, CN11.15, CN11.17, CN11.19, CN11.21, CN11.23, CN11.25, CN11.27, CN11.29, CN11.31, CN11.33, CN12.2, CN12.3, CN13.6, CN14.2, CN14.3, CN15.4, D501.2, E101.2, E102.2, E103.2, E104.2, E105.2, E106.2, E107.2, E108.2, E109.2, E110.2, E302.2, E303.2, E401.2, E402.2, E403.2, E404.2, E405.2, E406.2, E407.2, E408.2, E411.2, E412.2, E413.2, E414.2, E415.2, E416.2, E417.2, E421.2, E422.2, E423.2, E424.2, E425.2, E426.2, E427.2, E431.2, E432.2, E433.2, E434.2, E435.2, E441.2, E442.2, E443.2, E444.2, E501.2, E502.2, E503.2, E511.2, E512.2, E513.2, E514.2, E515.2, E516.2, E517.2, E518.2, E519.2, E520.2, E521.2, E522.2, E523.2, E524.2, E531.2, E532.2, E533.2, E534.2, E535.2, E536.2, E537.2, E538.2, E601.2, E602.2, E611.2, E612.2, E613.2, E614.2, E615.2, E616.2, E617.2, E618.2, E619.2, E620.2, E621.2, E622.2, E623.2, E624.2, E625.2, E626.2, E631.2, E632.2, E666.2, E702.2, E703.2, E704.2, E791.2, E792.2, E793.2, E794.2, FB101.2, FB102.2, FB802.2, HY1.1, HY1.22, JP7A1.3, JP9.1, LF1.8, MT1.1, MT2.1, MT4.1, MT5.1, MT6.1, MT7.1, P1.1, P1.2, P1.3, P1.4, P1.13, P1.25, P1.37, P1.49, P1.61, P1.73, P1.85, P9.3, P9.4, P9.21, P9.22, P9.34, P9.53, P9.54, Q501.1, Q711.1, R409.2, R501.1, RP101.10, RP102.10, RP104.10, RP105.10, RP106.10, RP107.10, RP108.10, RP109.10, RP110.10, RP111.10, RP401.10, TC9.2, U1.16, U1.53, U2.41, U2.58, U2.82, U3.8, U4.37, U5.1, U5.24, U5.40, U6.11, U6.12, U6.31, U7.1, U8.1, U9.9, U10.10, U11.10, U12.10, U13.10, U15.8, U15.15, U16.16, U16.20, U17.16, U17.20, U18.16, U18.20, U19.16, U19.20, U20.16, U20.20, U21.16, U21.20, U22.16, U22.20, U23.16, U23.20, U32.8, U33.8, U33.15, U34.1, U34.10, U35.1, U35.10, U35.19, U36.7, U37.7, U37.10, U37.13, U38.7, U39.7, U40.10, U40.19, U41.10, U41.19, U42.1, X1.1, X1.2
GNDA: C301.2, C302.1, C303.2, C304.1, C305.2, C306.2, C308.2, C311.2, C312.2, C313.2, C314.2, C323.2, C333.2, E305.2, E306.2, FB802.1, R304.1, R325.2, R335.2, U3.34
M0H: E443.3, U4.9
M0V: E441.3, U4.38
M1H: E442.3, U4.8
M1V: E444.3, U4.39
unnamed: BT9.1, D913.2
unnamed: C2.1, E101.3, U2.15
unnamed: C3.1, C307.1, R303.2, R309.2, U3.27
unnamed: C9.1, C913.1, D912.1, D913.1, U9.18
unnamed: C33.1, E407.3, U33.16
unnamed: C308.1, Q301.3, R308.1, R326.2, R336.2
unnamed: C321.1, Q321.1, R321.1, R322.2, U14.14
unnamed: C321.2, E306.3, R321.2, U14.13
unnamed: C322.1, C323.1, C324.1, C325.2, U14.1, U14.2
unnamed: C322.2, R322.1, R323.2
unnamed: C324.2, C325.1, JP10B1.1, R324.2
unnamed: C331.1, Q331.1, R331.1, R332.2, U14.8
unnamed: C331.2, E305.3, R331.2, R339.1, U14.9
unnamed: C332.1, C333.1, C334.1, C335.2, U14.6, U14.7
unnamed: C332.2, R332.1, R333.2
unnamed: C334.2, C335.1, R334.2
unnamed: C401.1, HY1.21, R405.2
unnamed: C411.1, CN1.6, E415.1
unnamed: C412.1, CN1.5, E417.1
unnamed: C413.1, CN1.9, E416.3
unnamed: C421.1, CN2.6, E425.3
unnamed: C422.1, CN2.5, E427.1
unnamed: C423.1, CN2.9, E426.1
unnamed: C501.2, CN6.18
unnamed: C502.1, CN6.11
unnamed: C701.1, E110.3, X1.4
unnamed: C711.1, R711.1, U42.2
unnamed: C712.1, R712.1, U42.6
unnamed: C713.1, U42.5
unnamed: C800.1, CN8.4, LF1.1
unnamed: C800.2, CN8.1, LF1.2
unnamed: C911.2, U9.17, Y9.3
unnamed: CN1.1, E411.1
unnamed: CN1.2, E412.1
unnamed: CN1.3, E413.3
unnamed: CN1.4, E414.3
unnamed: CN1.7, E401.3
unnamed: CN2.1, E421.1
unnamed: CN2.2, E422.1
unnamed: CN2.3, E423.1
unnamed: CN2.4, E424.1
unnamed: CN2.7, E408.3
unnamed: CN3.1, E303.3
unnamed: CN4.1, E302.3
unnamed: CN5.1, E611.3
unnamed: CN5.2, E612.3
unnamed: CN5.8, E613.3
unnamed: CN5.9, E614.3
unnamed: CN5.10, E615.3
unnamed: CN5.11, E616.3
unnamed: CN5.12, E601.3
unnamed: CN5.13, E617.3
unnamed: CN5.14, E618.3
unnamed: CN5.15, E619.3
unnamed: CN5.16, E620.3
unnamed: CN5.17, E621.3
unnamed: CN5.18, E622.3
unnamed: CN5.19, E623.3
unnamed: CN5.20, E624.3
unnamed: CN5.21, E625.3
unnamed: CN5.22, E626.3
unnamed: CN5.23, E602.3
unnamed: CN6.22, E538.3
unnamed: CN7.1, E511.3
unnamed: CN7.2, E512.3
unnamed: CN7.3, E513.3
unnamed: CN7.4, E514.3
unnamed: CN7.5, E515.3
unnamed: CN7.6, E516.3
unnamed: CN7.7, E517.3
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

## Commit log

2019-04-14 Initial commit of this crazy project
    [Raemix500.kicad_pcb, Raemix500.sch, cpu.sch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]
2019-04-14 Add Denise & Video
    [Raemix500.kicad_pcb, Raemix500.sch, cpu.sch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]
2019-04-15 Add Paula and Joystick Ports, audio filters still missing
    [Paula & Audio Stuff.sch, Raemix500.sch, cpu.sch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]
2019-04-15 Add Agnus VBB cap value
    [cpu.sch]
2019-04-15 Add audio filters
    [Paula & Audio Stuff.sch, video.sch]
2019-04-16 Rename audio schematics
    [Raemix500.sch, audio.sch]
2019-04-16 Add CIAs, Parallel port and part of Serial port
    [Raemix500.sch, audio.sch, cias.sch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]
2019-04-17 Complete Serial port
    [audio.sch, cias.sch]
2019-04-17 Add keyboard connector
    [cias.sch]
2019-04-17 Add power-on reset
    [cias.sch]
2019-04-17 Add floppy stuff, not yet complete
    [Raemix500.sch, audio.sch, cias.sch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]
2019-04-18 Fix some references
    [cias.sch, cpu.sch, floppy.sch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]
2019-04-20 Add terminators and ROM, fix bus interconnections
    [Raemix500.sch, audio.sch, cias.sch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]
2019-04-20 Add clock distribution
    [Raemix500.sch, audio.sch, cias.sch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]
2019-04-20 Add main crystal
    [cpu.sch]
2019-04-20 Fix some symbols
    [clockdist.sch, cpu.sch]
2019-04-20 Add video power
    [audio.sch, cias.sch, clockdist.sch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]
2019-04-20 Add expansion bus
    [Raemix500.sch, audio.sch, cias.sch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]
2019-04-20 Add power & decoupling, not yet complete
    [Raemix500.sch, audio.sch, cias.sch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]
2019-04-23 Add power input and complete clock distribution
    [audio.sch, clockdist.sch, power.sch]
2019-04-23 Add RTC
    [Raemix500.sch, audio.sch, cias.sch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]
2019-04-23 Add trapdoor connector
    [Raemix500.sch, audio.sch, cias.sch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]
2019-04-24 Replace RAM with original design
    [expansion.sch, ram.sch, trapdoor.sch]
2019-05-01 Complete RAM
    [ram.sch]
2019-05-01 Fix some RAM signals
    [ram.sch]
2019-05-01 Add images with quotes (Thanks @screwbreaker!)
2019-05-02 Add external floppy connector (and do a few fixes)
    [cias.sch, floppy.sch, video.sch]
2019-05-02 Add composite output
    [floppy.sch, ram.sch, video.sch]
2019-05-07 Add work-in-progress PCB
2019-05-07 Fix Bridged Jumper footprint
2019-05-07 Fix power-up reset
    [Raemix500.sch, audio.sch, cias.sch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]
2019-05-08 Work in progress
    [audio.sch, cias.sch, clockdist.sch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]
2019-05-08 Work on joystick ports
    [audio.sch]
2019-05-09 Almost all components positioned
    [audio.sch, cias.sch, clockdist.sch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]
2019-05-12 Top layer done!
    [audio.sch, cpu.sch, power.sch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]
2019-05-13 Add some labels and improve AGND/GND separation
2019-05-13 Place RP109/111 better
    [Raemix500.kicad_pcb]
2019-05-13 Add some tracks that got lost
    [Raemix500.kicad_pcb]
2019-05-13 Begun work on bottom layer
    [audio.sch]
2019-06-23 Almost there :)
    [audio.sch, cias.sch, floppy.sch]
2019-06-23 Complete top audio ground and fix some mistakes
    [expansion.sch]
2019-06-23 Fix expansion connector
2019-06-23 Erm, fix expansion connector grounds
2019-06-23 Fix shielding of D-Sub connectors
    [audio.sch, cias.sch, video.sch]
2019-06-23 Fix bottom audio ground
2019-07-22 Fix typo
    [ram.sch]
2019-07-22 Wire Power Connector (Original+DIN-5)
    [power.sch]
2019-07-22 Fix power connector label
    [power.sch]
2019-07-22 Fix keyboard connector key pin
    [cias.sch]
2019-07-22 Add C99 on PCB
    [cpu.sch]
2019-11-07 Add (hopefully) all vias between ground layers
2019-11-09 Add missing via in audio ground section
2020-04-04 Fix a lot of ERC/DRC errors
    [Raemix500.sch, audio.sch, cias.sch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]
2020-04-04 Fix misaligned pad on expansion connector
2020-04-04 Replace audio/composite jacks with A600's - This means PCB IS READY! Still need to fix the silkscreen though...
    [PJRAN1X1U01X--3DModel-STEP-56544.stp, audio.sch, video.sch]
2020-04-05 Use KiCad footprint for oscillator
    [cpu.sch, power.sch]
2020-04-05 Use proper trapdoor footprint at last
    [audio.sch, trapdoor.sch]
2020-04-05 Switch back to SOD27 footprint for D913
    [rtc.sch]
2020-04-05 Avoid battery holder crashing into C12
2020-04-05 Fix JP7A/B
    [cias.sch, trapdoor.sch]
2020-04-05 Start polishing silkscreen; all ICs and connectors done
2020-04-06 Work on silkscreen and some minor fixes
2020-04-11 Almost ready for V1
    [BS-7.STEP]
2020-04-11 Add OSHW & KiCad logos
    [Raemix500.sch]
2020-04-11 Add logos and credits
    [Raemix500.sch]
2020-04-11 Erm, fix a huge mistake in the audio part and some refinements
    [audio.sch]
2020-04-11 Minor corrections
    [expansion.sch]
2020-04-12 Raemix500 -> Raemixx500
    [Raemix500.sch, Raemixx500.sch]
2020-04-12 Ready for V1
    [Raemixx500.sch, audio.sch, cias.sch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]
2020-04-15 Add some info and fix PCBWay board link
2020-04-18 Redo power connector and some cosmetic fixes here and there
    [power.sch]
2020-04-18 Fix wrong symbols in schematics - Does not impact PCB
    [cias.sch]
2020-04-19 Begin adding part numbers
    [Raemixx500.sch, audio.sch, cias.sch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]
2020-04-19 More part numbers
    [cias.sch, power.sch, ram.sch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]
2020-04-19 Use 12.5mm footprints for C401/2 - Closes #16
    [video.sch]
2020-04-19 Use D12.5mm for C307 as well
    [audio.sch]
2020-04-19 Guess what???
    [video.sch]
2020-04-19 Add EMI filter types
    [audio.sch, cias.sch, clockdist.sch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]
2020-04-23 Add part numbers for EMI filters Not the original filters, but what seem to be suitable replacements available today
    [audio.sch, cias.sch, clockdist.sch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]
2020-04-23 Fix note on power connector
2020-04-26 Add EMI filter 3D models, add logo, re-add Rock Lobster (closes #15) Thanks to Szabó Zoltán and Workshopshed!
    [DSN6.FCStd, DSN6.step, DSS6.FCStd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]
2020-04-26 Make DSS 3d model slightly narrower, add E501/2/3
    [DSS6.FCStd, DSS6.step]
2020-04-26 Use full IDC connector for floppy and some cosmetic fixes
    [floppy.sch]
2020-05-01 Cosmetic fixes and add missing (but harmless) track
2020-05-01 Increase ground fill clearance
2020-05-02 Make C712 footprint smaller
    [cias.sch]
2020-05-02 Add drive switcher
    [cias.sch]
2020-05-02 Add Kickstart switcher
    [rom.sch]
2020-05-02 Finalize ground fills
2020-05-02 I'm tired and I want to go to bed
2021-06-20 (Try to) Identify the minimum set of required components
    [audio.sch, cias.sch, clockdist.sch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]
2021-06-20 Rename "Optional" Field to "Section"
    [Raemixx500.sch, audio.sch, cias.sch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]
2021-06-20 RP104 -> 470R
    [terminators.sch]
2021-06-20 Switch to the CC BY-NC-SA 4.0 License Please note that COMMERCIAL USE OF THIS WORK IS PROHIBITED starting from this commit, except as stated in the README.
    [Raemixx500.sch, audio.sch, cias.sch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]
2021-06-20 Make pin holes for DB-23 connectors 1.2mm in diameter This is because the original DB-23 connectors used by Commodore seem to have thicker pins
2021-06-20 Add alternative SMT footprints for Q321/331
    [audio.sch]
2021-06-20 Add alternative footprint for modern equivalent of line filter
    [power.sch]
2021-06-20 Add ESD protection on joystick/mouse ports
    [audio.sch]
2021-06-20 Add optional buffer for HSYNC/VSYNC
    [video.sch]
2021-06-20 Restore Line Filter 3D model
2021-06-20 Make ground plane (slightly) less intrusive
2021-06-20 Add ground track between HSYNC and VSYNC to avoid inducted noise
2021-06-20 Reposition some ground vias
2021-06-20 Add labels on all resistors, caps and ICs + More work on silkscreen
    [cias.sch]
2021-06-20 Add connector to blink the Floppy LED on HD activity
    [cias.sch]
2021-06-20 Add missing connection (Thanks @LIV2!)
    [cias.sch]
2021-06-20 Some more work on silkscreen
    [ram.sch]
2021-06-20 Add RTC crystal frequency on silkscreen
    [rtc.sch]
2021-06-20 Add model on silkscreen for SMD ICs
    [video.sch]
2021-06-20 Make dimensions the *very* same as the original board and (try to) place connectors better This was a HUUUUUUUUUUUGE work, hopefully we didn't break anything and the joystick ports will now fit bette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
    [audio.sch, video.sch]
2021-06-20 Replace OSHW logo with CC-BY-NC-SA logo - Ready for V2B Sigh.
    [Raemixx500.sch]
2021-06-20 Fix some interruptions in ground plane
2021-06-20 Restore ground plane on left edge and near trapdoor
2021-12-21 Update board link

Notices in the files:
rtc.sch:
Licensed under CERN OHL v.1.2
